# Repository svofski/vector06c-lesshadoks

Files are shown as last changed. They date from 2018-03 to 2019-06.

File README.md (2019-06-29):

ЛЕШАДОК ПОМПЕ
=============

ЛЕШАДОК ПОМПЕ (Les shadoks pompaient) is an expansion board for Вектор-06ц home computer from USSR era.

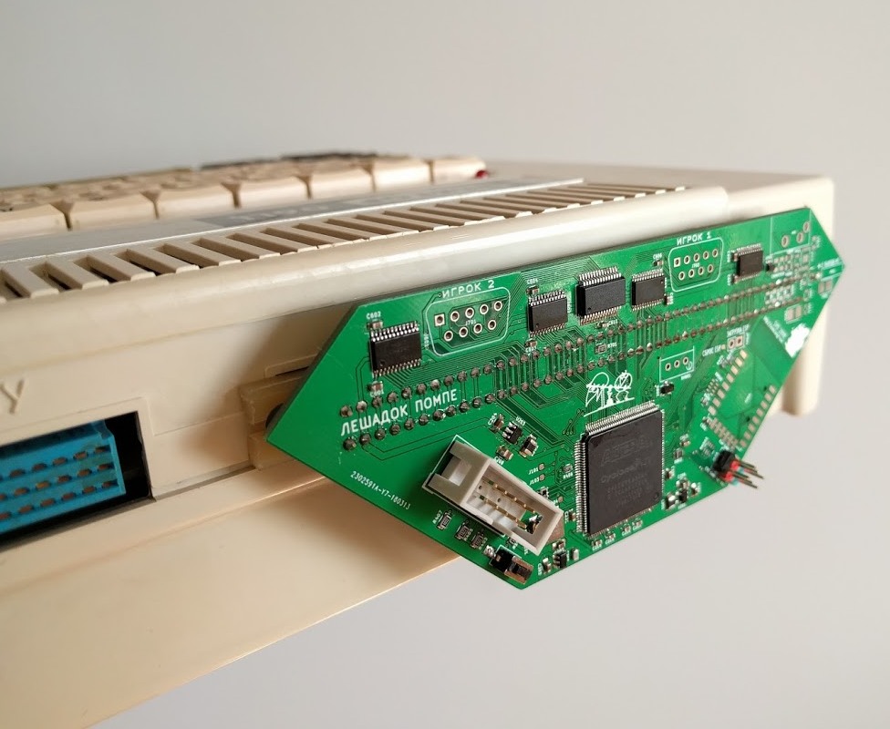
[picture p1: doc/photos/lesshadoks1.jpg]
ЛЕШАДОК ПОМПЕ


Features (real and planned):
  - [x] RAM disk expansion in SDRAM
  - [x] AY and other sound device emulation
  - [x] Joystick ports
  - [x] floppy disk emulator
  - [x] floppy images on SD card
  - [ ] floppy images downloaded from the internets
  - [x] ESP12F working as FPGA configurator
  - [x] ESP12F as user interface for SD card image selection
  - [ ] ESP12F for uploading floppy disk images to SDRAM
  - [ ] VI53 sound passthrough
  
Key hardware features:
  * Main chip: EP4CE6 Intel Cyclone IV device
  * 8MB SDRAM (working at 96MHz)
  * ESP12F module
  * Audio output with amplifier
  * Analog input for internal audio mixing (using LVDS sigma-delta ADC)

Board schematic
---------------
[Schematic](/kicad/shadok-cheap/shadok.pdf) (pdf)

Build instructions
------------------
This project consists of many parts and putting it together is not a simple task.
Here I wrote down some instructions primarily for myself to be able to remember
what to do. Good luck!

### PART 1 Building Cosmogol999 (esp8266 firmware)

1. Get the sources
```
git clone --recurse-submodules https://github.com/svofski/vector06c-lesshadoks
```

2. Prepare esp-open-sdk
Follow instructions at https://github.com/pfalcon/esp-open-sdk.
Mind the requirements, then get the SDK and build:
```
git clone --recursive --depth=1 https://github.com/pfalcon/esp-open-sdk.git
cd esp-open-sdk
make STANDALONE=y
```

After the toolchain is ready, do as it says:
```
export PATH=$HOME/esp-open-sdk/xtensa-lx106-elf/bin:$PATH
```
Also export SDK_BASE:
```
export SDK_BASE=$HOME/esp-open-sdk/ESP8266_NONOS_SDK-2.1.0-18-g61248df
```

3. Actually build

```
cd $HOME/vector06c-lesshadoks/esp8266/cosmogol999
make 
``` 

The firmware will be found in 
```
    rboot/firmware/rboot.bin
    firmware/shadki.bin
    blank_config.bin
```

6. Flash
```
make flash
```
This probably will do something destructive to your esp12f.

### PART 2 Building floppy emulator firmware

This one should be easy.
```
cd $HOME/vector06c-lesshadoks/6502
make
```

### PART 3 Building the FPGA programming files

1. Get and install Quartus Lite that supports Cyclone IV E (e.g. 17.1)

2. For the time being there is no makefile, so just open the project 
quartus/pompaient.qpf and press Ctrl-L.

### PART 4 Put it all together

???

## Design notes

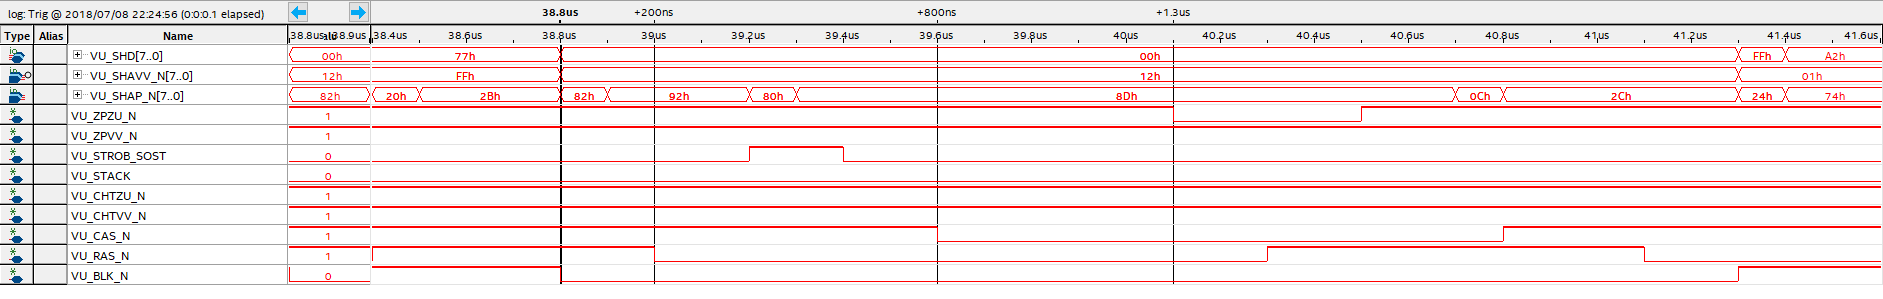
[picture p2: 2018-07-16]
doc/buscaptures/kvaz-write-to-1234-as-ram.png

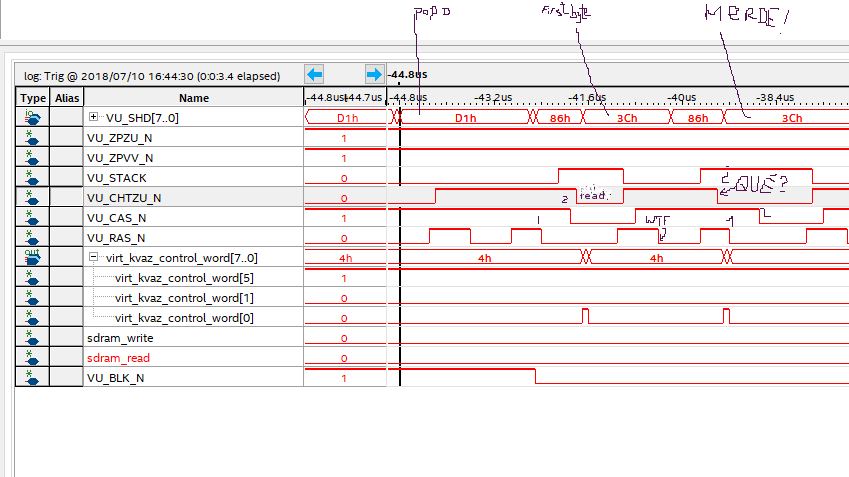
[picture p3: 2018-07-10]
doc/buscaptures/pop-merde.png

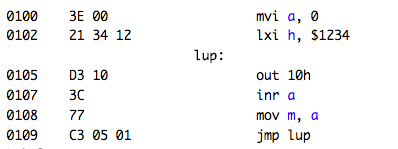
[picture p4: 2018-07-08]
doc/buscaptures/count-and-sta-code.png

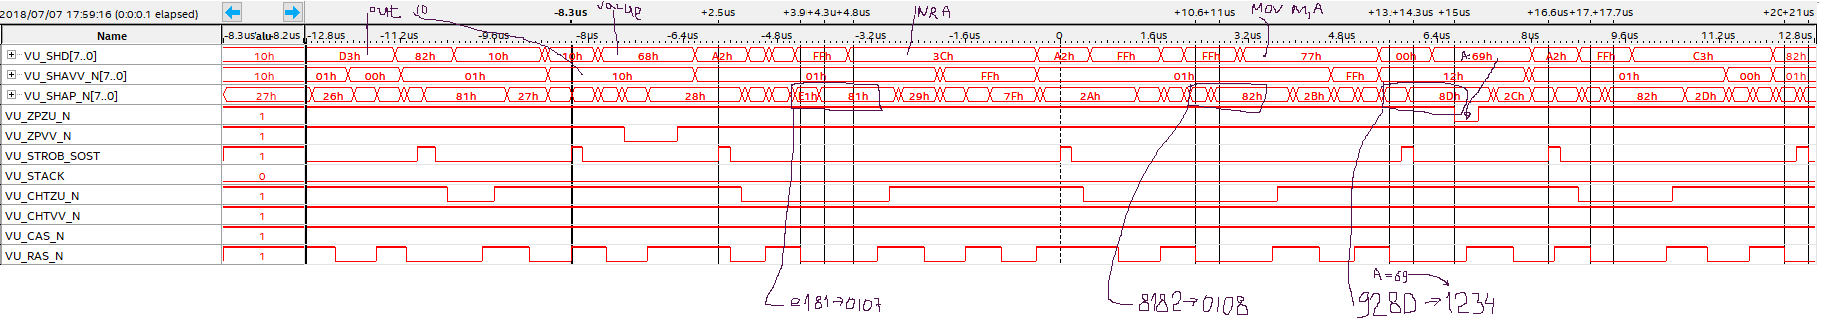
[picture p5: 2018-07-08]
doc/buscaptures/count-and-sta.png

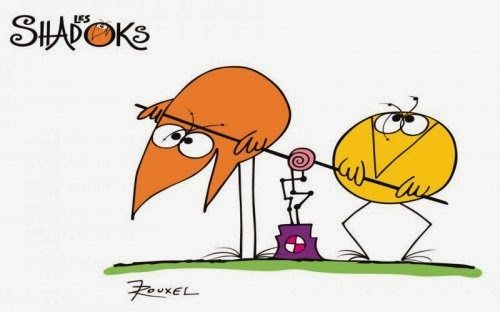
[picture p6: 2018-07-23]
esp8266/cosmogol999/html/shadoks/pompaient.jpg

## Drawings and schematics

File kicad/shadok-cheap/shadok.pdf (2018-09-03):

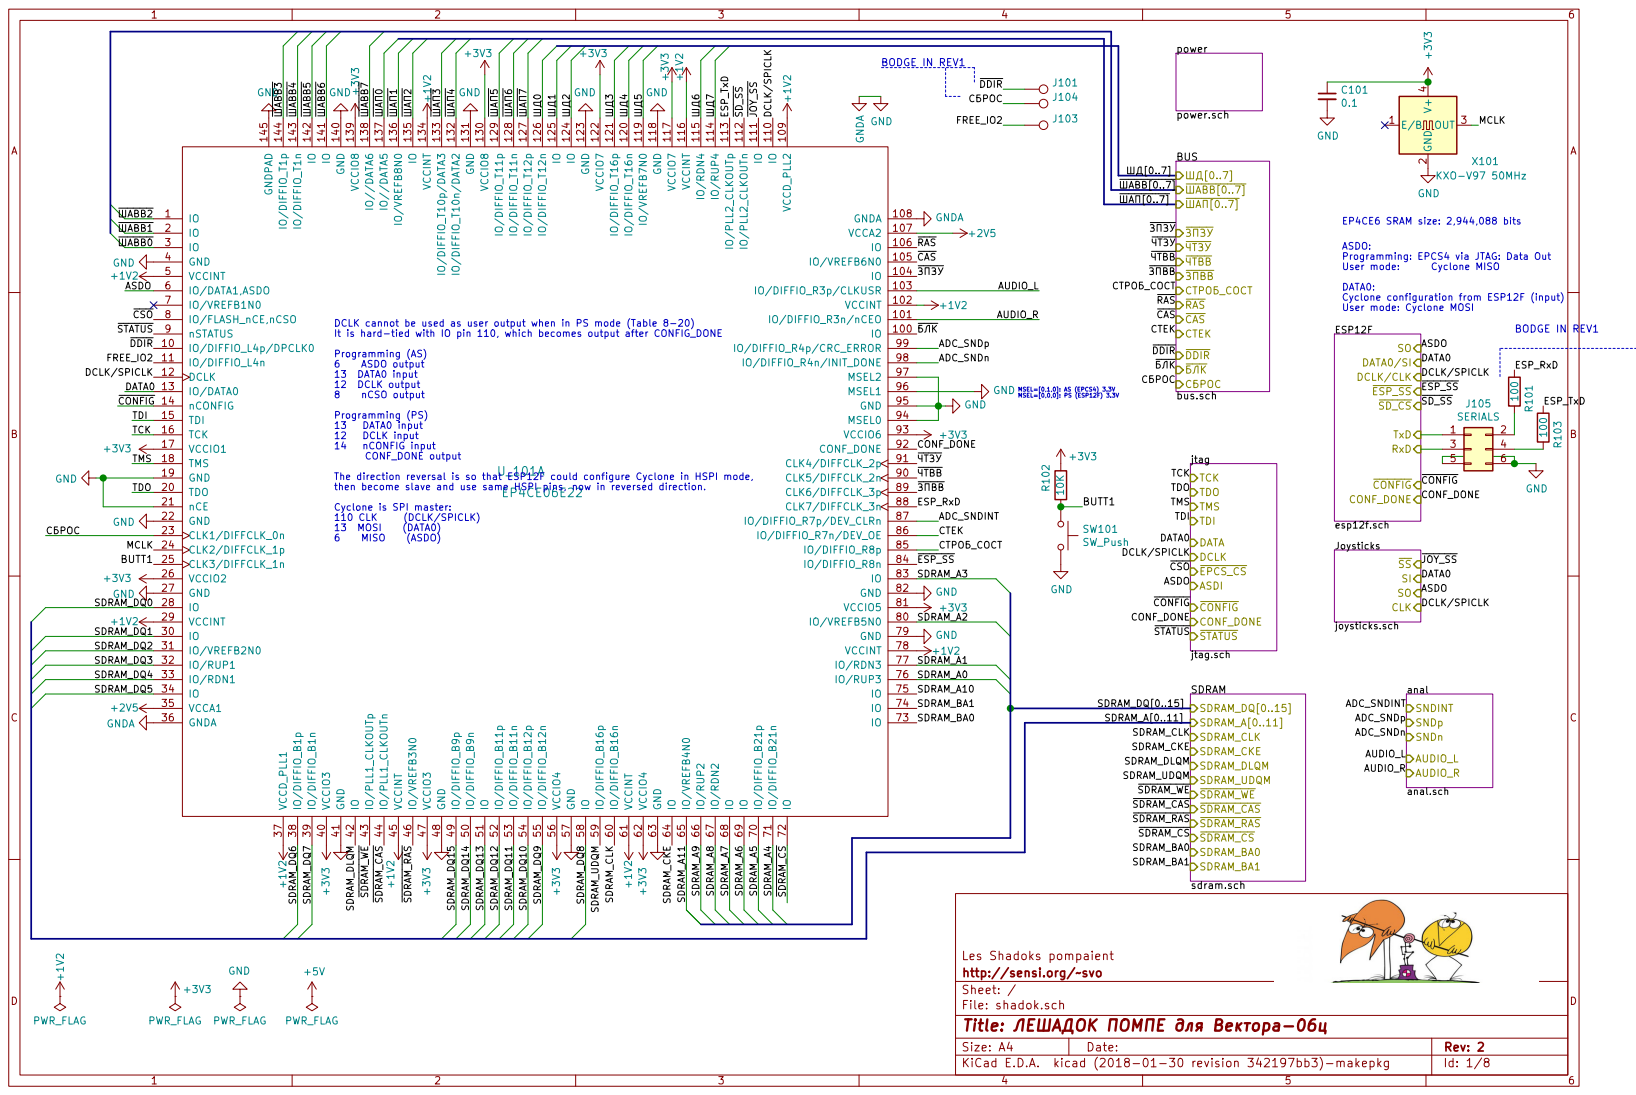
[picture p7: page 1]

BODGE IN REV1

EP4CE6 SRAM size: 2,944,088 bits DCLK cannot be used as user output when in PS mode (Table 8-20)

esp12f.sch DCLK/CLK DATA0/SI CONFIG

DATA0: Cyclone configuration from ESP12F (input) User mode: Cyclone MOSI DCLK/SPICLK DATA0 CONFIG

It is hard-tied with IO pin 110, which becomes output after CONFIG_DONE
Programming (AS) 6 ASDO output 13 DATA0 input 12 DCLK output 8 nCSO output Programming (PS) 13 DATA0 input 12 DCLK input 14 nCONFIG input

CONF_DONE output The direction reversal is so that ESP12F could configure Cyclone in HSPI mode,

joysticks.sch CLK
anal anal.sch SNDINT SNDp SNDn AUDIO_L AUDIO_R

Les Shadoks pompaient
File: shadok.sch Sheet: / http://sensi.org/svo

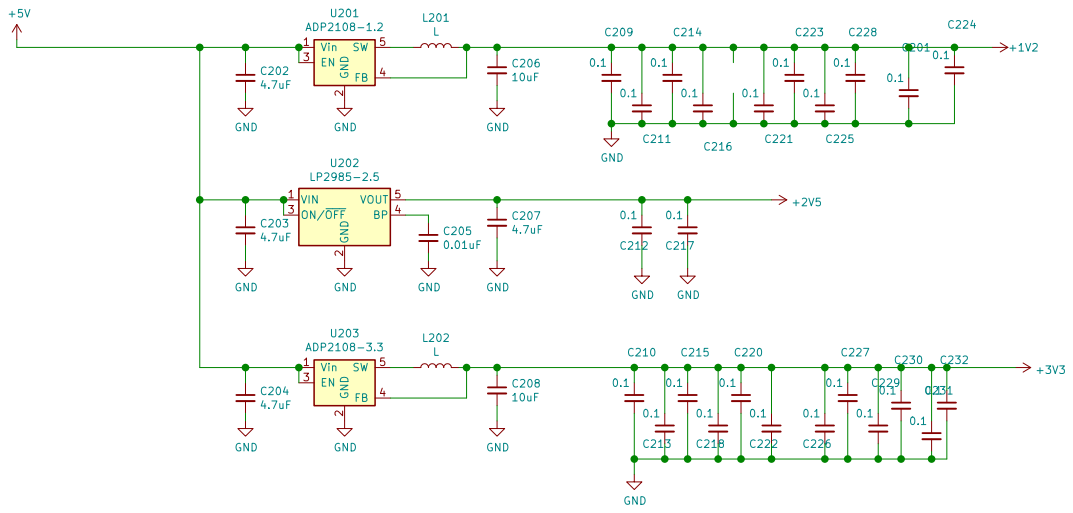
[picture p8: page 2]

2 EN 3 FB 4 SW 5 U201 ADP2108-1.2 Vin 1 GND
L GND GND GND

2 ON/OFF 3 BP 4 VOUT 5 U202

2 EN 3 FB 4 SW 5 U203 ADP2108-3.3 VIN 1 GND

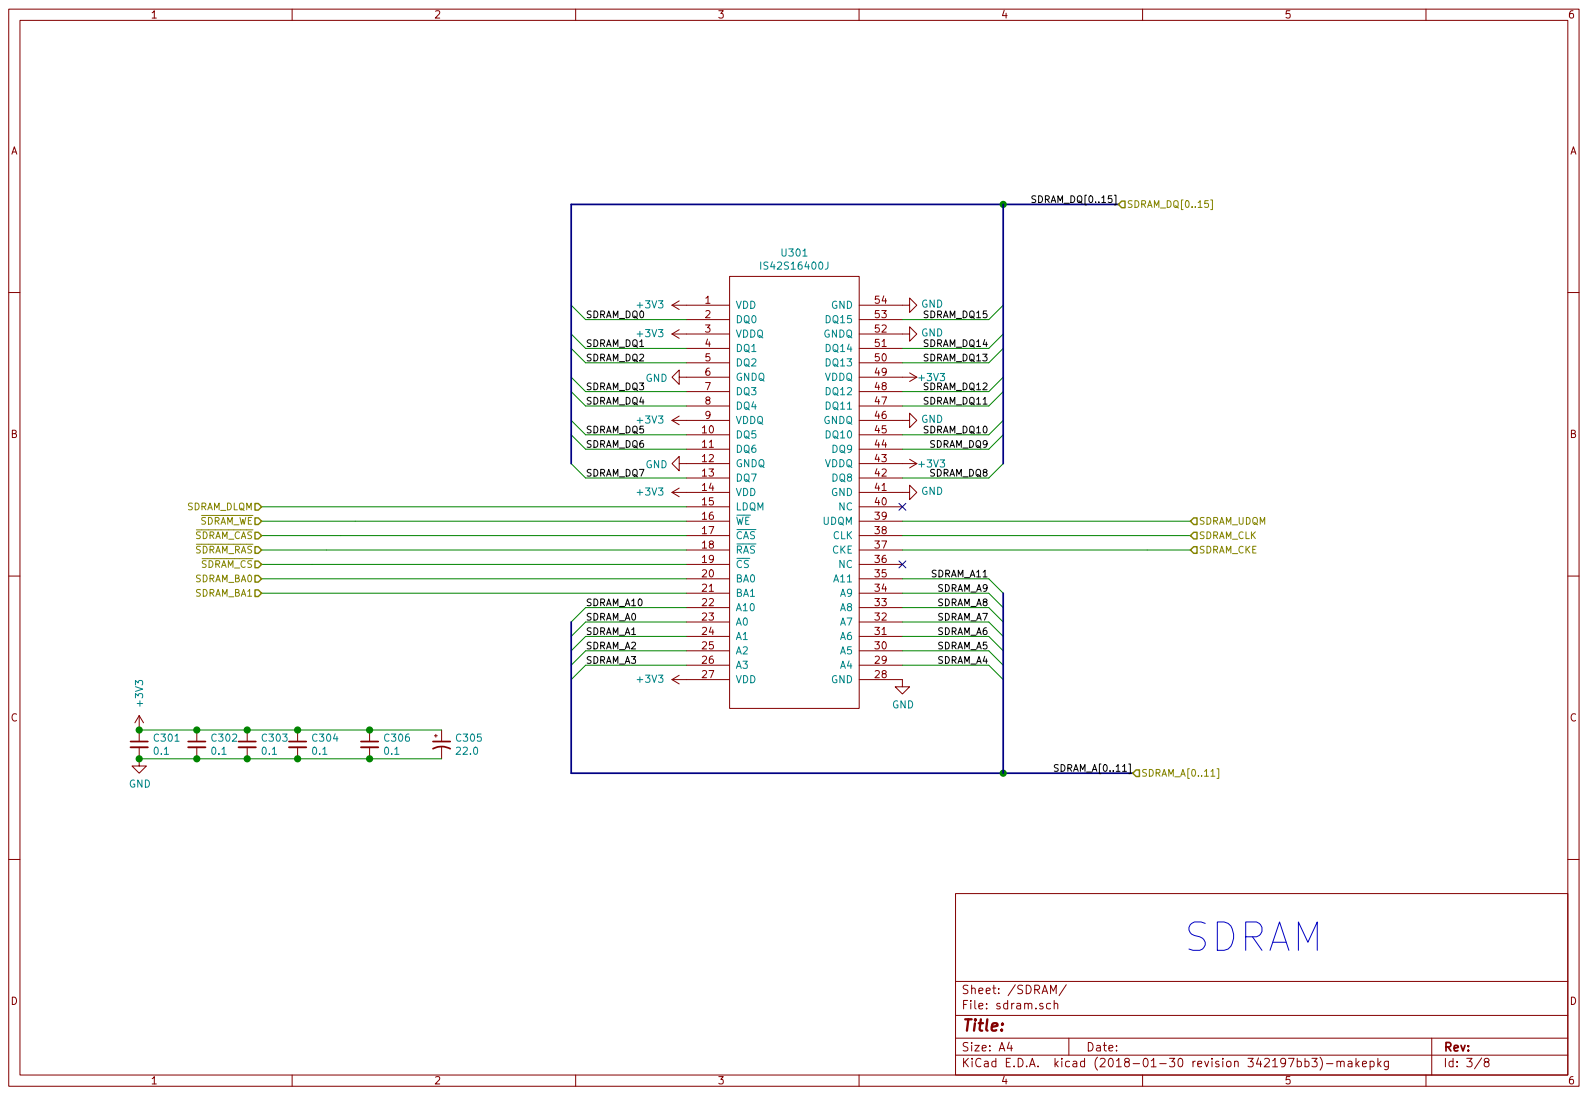
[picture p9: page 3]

Id: 3/8 Title: File: sdram.sch Sheet: /SDRAM/

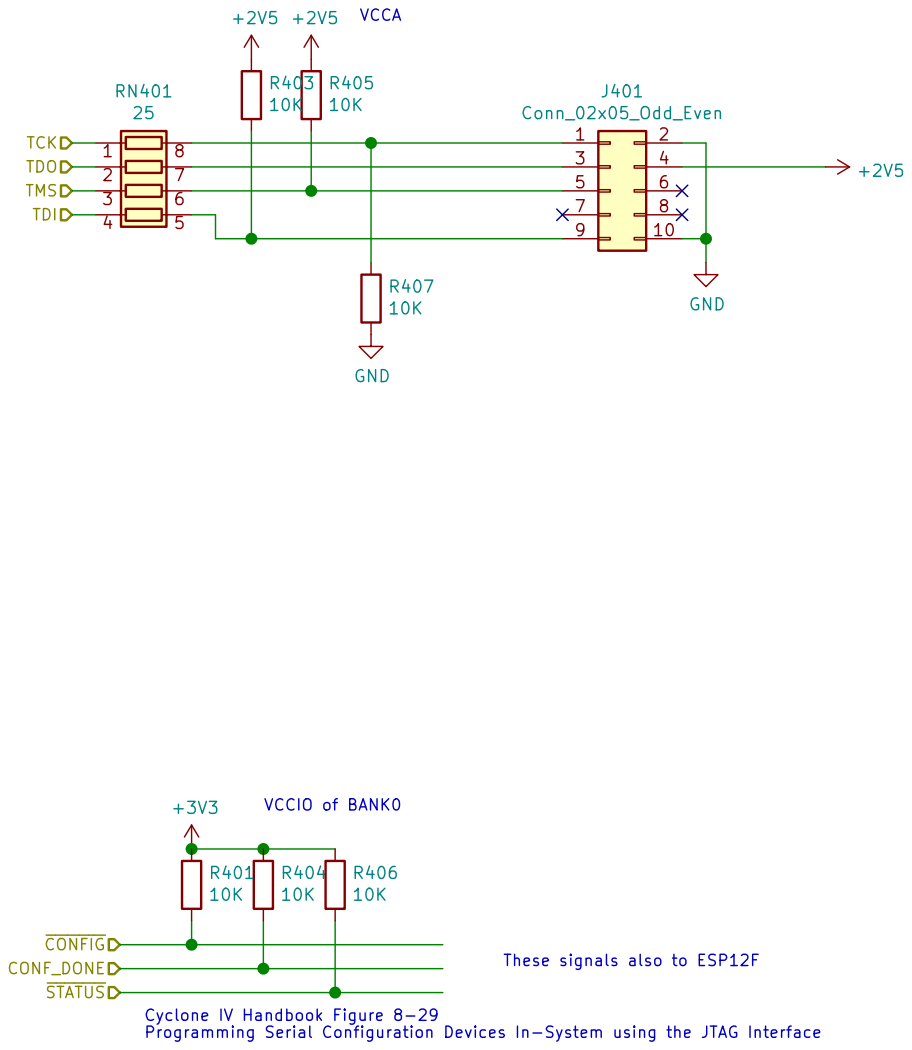
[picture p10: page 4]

7 | | 5 | 6 8 10
6 | | 7 9

These signals also to ESP12F R404

Programming Serial Configuration Devices In-System using the JTAG Interface

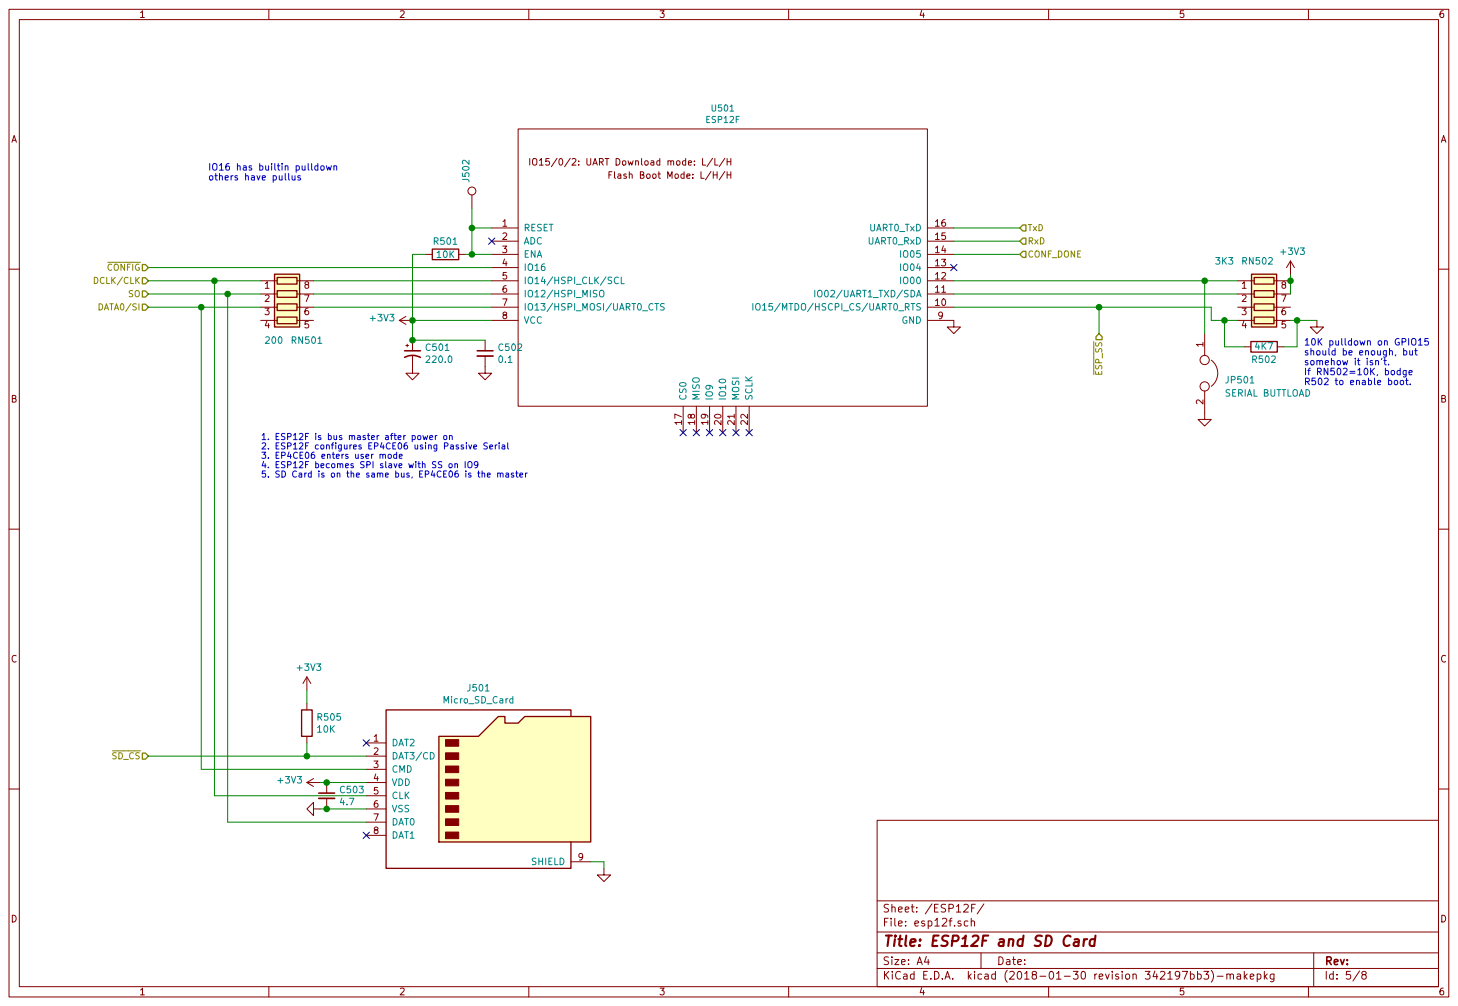
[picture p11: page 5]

should be enough, but somehow it isn't.
If RN502=10K, bodge R502 to enable boot.

1. ESP12F is bus master after power on
2. ESP12F configures EP4CE06 using Passive Serial 3. EP4CE06 enters user mode
4. ESP12F becomes SPI slave with SS on IO9

File: esp12f.sch Sheet: /ESP12F/
Id: 5/8 Title: ESP12F and SD Card

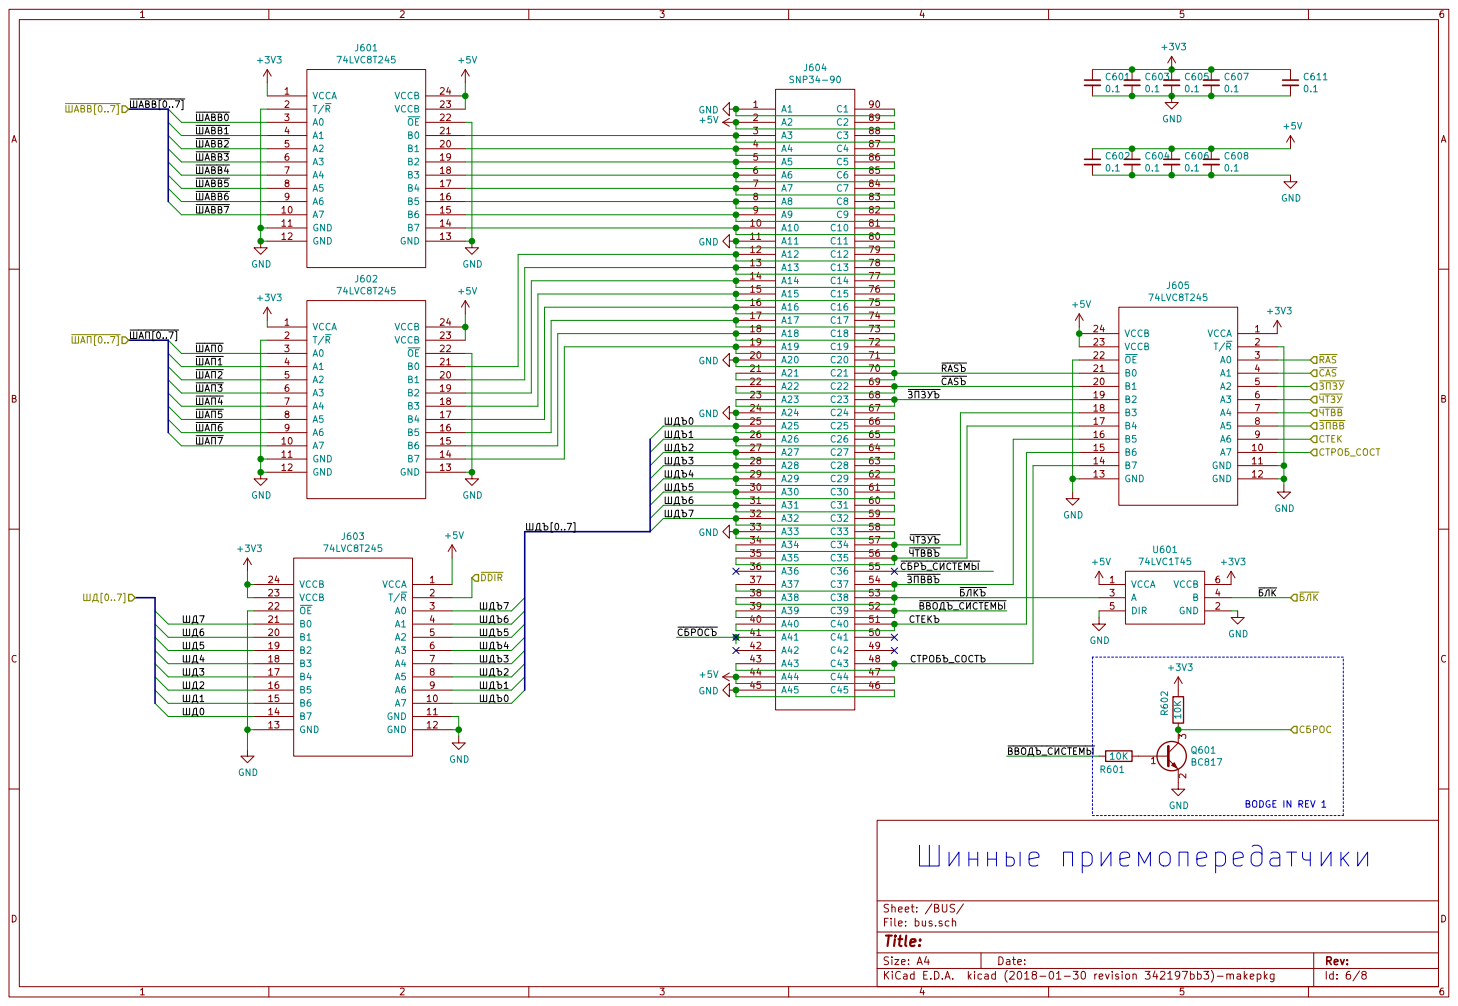
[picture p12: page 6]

J604 SNP34-90 GND GND GND GND GND GND

Id: 6/8 Title: File: bus.sch Sheet: /BUS/

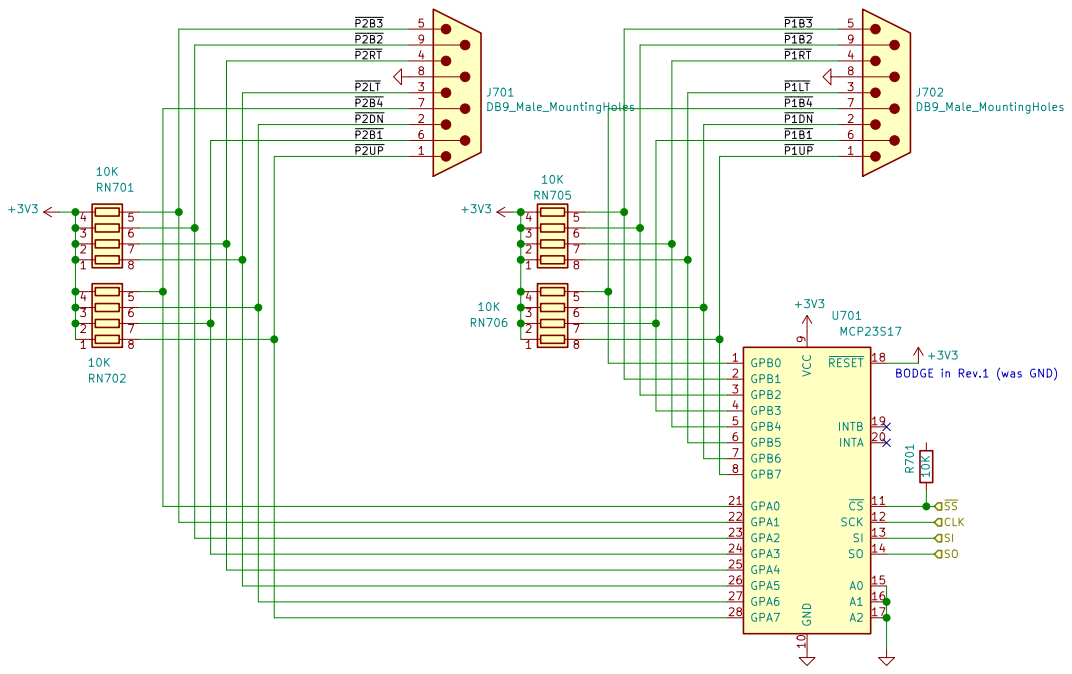
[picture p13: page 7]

File: joysticks.sch
Id: 7/8 Title: Joystick ports

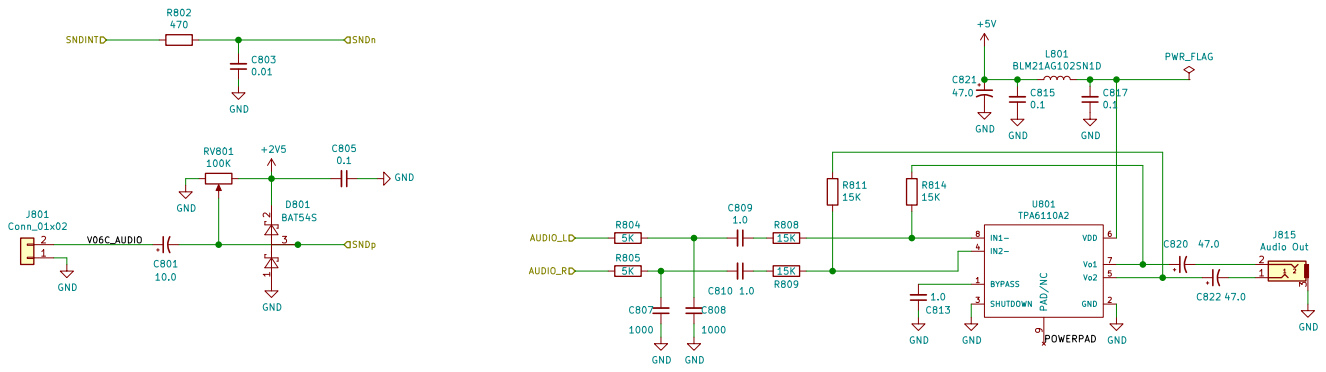
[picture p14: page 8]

File: anal.sch Sheet: /anal/
Id: 8/8 Title: Analog I/O

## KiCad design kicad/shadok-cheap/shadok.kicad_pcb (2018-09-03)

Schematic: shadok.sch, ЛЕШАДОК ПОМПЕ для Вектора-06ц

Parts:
C101: 0.1; C_0603
J101, J103, J104: TEST_1P; WIREPAD_SMD_TINY
J105: SERIALS; Pin_Header_Straight_2x03
R101, R103: 100; R_0805
R102: 10K; R_0805
SW101: SW_Push; SW_SPST_FSMSM
U_101: EP4CE06E22; Altera_EQFP-144_20x20mm_Pitch0.5mm
X101: KXO-V97 50MHz; KXO-V97

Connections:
+1V2: U_101.5, U_101.29, U_101.37, U_101.45, U_101.61, U_101.78, U_101.102, U_101.109, U_101.116, U_101.134; also elsewhere on the board
+2V5: U_101.35, U_101.107; also elsewhere on the board
+3V3: C101.1, R102.2, U_101.17, U_101.26, U_101.40, U_101.47, U_101.56, U_101.62, U_101.81, U_101.93, U_101.117, U_101.122, U_101.130, U_101.139, X101.4; also elsewhere on the board
/ADC_SNDINT: U_101.87; also elsewhere on the board
/ADC_SNDn: U_101.98; also elsewhere on the board
/ADC_SNDp: U_101.99; also elsewhere on the board
/ASDO: U_101.6; also elsewhere on the board
/AUDIO_L: U_101.103; also elsewhere on the board
/AUDIO_R: U_101.101; also elsewhere on the board
/BUTT1: R102.1, SW101.1, U_101.25
/CONF_DONE: U_101.92; also elsewhere on the board
/DATA0: U_101.13; also elsewhere on the board
/DCLK/SPICLK: U_101.12, U_101.110; also elsewhere on the board
/ESP12F/RxD: J105.3; also elsewhere on the board
/ESP12F/TxD: J105.1; also elsewhere on the board
/ESP_RxD: R101.1, U_101.88
/ESP_TxD: R103.1, U_101.113
/FREE_IO2: J103.1, U_101.11
/MCLK: U_101.24, X101.3
/SDRAM_A0: U_101.76; also elsewhere on the board
/SDRAM_A1: U_101.77; also elsewhere on the board
/SDRAM_A2: U_101.80; also elsewhere on the board
/SDRAM_A3: U_101.83; also elsewhere on the board
/SDRAM_A4: U_101.71; also elsewhere on the board
/SDRAM_A5: U_101.70; also elsewhere on the board
/SDRAM_A6: U_101.69; also elsewhere on the board
/SDRAM_A7: U_101.68; also elsewhere on the board
/SDRAM_A8: U_101.67; also elsewhere on the board
/SDRAM_A9: U_101.66; also elsewhere on the board
/SDRAM_A10: U_101.75; also elsewhere on the board
/SDRAM_A11: U_101.65; also elsewhere on the board
/SDRAM_BA0: U_101.73; also elsewhere on the board
/SDRAM_BA1: U_101.74; also elsewhere on the board
/SDRAM_CKE: U_101.64; also elsewhere on the board
/SDRAM_CLK: U_101.60; also elsewhere on the board
/SDRAM_DLQM: U_101.42; also elsewhere on the board
/SDRAM_DQ0: U_101.28; also elsewhere on the board
/SDRAM_DQ1: U_101.30; also elsewhere on the board
/SDRAM_DQ2: U_101.31; also elsewhere on the board
/SDRAM_DQ3: U_101.32; also elsewhere on the board
/SDRAM_DQ4: U_101.33; also elsewhere on the board
/SDRAM_DQ5: U_101.34; also elsewhere on the board
/SDRAM_DQ6: U_101.38; also elsewhere on the board
/SDRAM_DQ7: U_101.39; also elsewhere on the board
/SDRAM_DQ8: U_101.58; also elsewhere on the board
/SDRAM_DQ9: U_101.55; also elsewhere on the board
/SDRAM_DQ10: U_101.54; also elsewhere on the board
/SDRAM_DQ11: U_101.53; also elsewhere on the board
/SDRAM_DQ12: U_101.52; also elsewhere on the board
/SDRAM_DQ13: U_101.51; also elsewhere on the board
/SDRAM_DQ14: U_101.50; also elsewhere on the board
/SDRAM_DQ15: U_101.49; also elsewhere on the board
/SDRAM_UDQM: U_101.59; also elsewhere on the board
/TCK: U_101.16; also elsewhere on the board
/TDI: U_101.15; also elsewhere on the board
/TDO: U_101.20; also elsewhere on the board
/TMS: U_101.18; also elsewhere on the board
/~CAS: U_101.105; also elsewhere on the board
/~CONFIG: U_101.14; also elsewhere on the board
/~CSO: U_101.8
/~DDIR: J101.1, U_101.10; also elsewhere on the board
/~ESP_SS: U_101.84; also elsewhere on the board
/~JOY_SS: U_101.111; also elsewhere on the board
/~RAS: U_101.106; also elsewhere on the board
/~SDRAM_CAS: U_101.44; also elsewhere on the board
/~SDRAM_CS: U_101.72; also elsewhere on the board
/~SDRAM_RAS: U_101.46; also elsewhere on the board
/~SDRAM_WE: U_101.43; also elsewhere on the board
/~SD_SS: U_101.112; also elsewhere on the board
/~STATUS: U_101.9; also elsewhere on the board
/~БЛК: U_101.100; also elsewhere on the board
/~ЗПВВ: U_101.89; also elsewhere on the board
/~ЗПЗУ: U_101.104; also elsewhere on the board
/~ЧТВВ: U_101.90; also elsewhere on the board
/~ЧТЗУ: U_101.91; also elsewhere on the board
/~ШАВВ0: U_101.3; also elsewhere on the board
/~ШАВВ1: U_101.2; also elsewhere on the board
/~ШАВВ2: U_101.1; also elsewhere on the board
/~ШАВВ3: U_101.144; also elsewhere on the board
/~ШАВВ4: U_101.143; also elsewhere on the board
/~ШАВВ5: U_101.142; also elsewhere on the board
/~ШАВВ6: U_101.141; also elsewhere on the board
/~ШАВВ7: U_101.138; also elsewhere on the board
/~ШАП0: U_101.137; also elsewhere on the board
/~ШАП1: U_101.136; also elsewhere on the board
/~ШАП2: U_101.135; also elsewhere on the board
/~ШАП3: U_101.133; also elsewhere on the board
/~ШАП4: U_101.132; also elsewhere on the board
/~ШАП5: U_101.129; also elsewhere on the board
/~ШАП6: U_101.128; also elsewhere on the board
/~ШАП7: U_101.127; also elsewhere on the board
/СБРОС: J104.1, U_101.23; also elsewhere on the board
/СТЕК: U_101.86; also elsewhere on the board
/СТРОБ_СОСТ: U_101.85; also elsewhere on the board
/ШД0: U_101.126; also elsewhere on the board
/ШД1: U_101.125; also elsewhere on the board
/ШД2: U_101.124; also elsewhere on the board
/ШД3: U_101.121; also elsewhere on the board
/ШД4: U_101.120; also elsewhere on the board
/ШД5: U_101.119; also elsewhere on the board
/ШД6: U_101.115; also elsewhere on the board
/ШД7: U_101.114; also elsewhere on the board
GND: C101.2, J105.5, J105.6, SW101.2, U_101.4, U_101.19, U_101.21, U_101.22, U_101.27, U_101.36, U_101.41, U_101.48, U_101.57, U_101.63, U_101.79, U_101.82, U_101.94, U_101.95, U_101.96, U_101.97, U_101.108, U_101.118, U_101.123, U_101.131, U_101.140, U_101.145, X101.2; also elsewhere on the board
unnamed: J105.2, R101.2
unnamed: J105.4, R103.2

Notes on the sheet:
MSEL=[0,1,0]: AS (EPCS4) 3.3V MSEL=[0,0,0]: PS (ESP12F) 3.3V
ASDO: Programming: EPCS4 via JTAG: Data Out User mode: Cyclone MISO DATA0: Cyclone configuration from ESP12F (input) User mode: Cyclone MOSI
EP4CE6 SRAM size: 2,944,088 bits
DCLK cannot be used as user output when in PS mode (Table 8-20) It is hard-tied with IO pin 110, which becomes output after CONFIG_DONE Programming (AS) 6 ASDO output 13 DATA0 input 12 DCLK output 8 nCSO output Programming (PS) 13 DATA0 input 12 DCLK input 14 nCONFIG input CONF_DONE output The dire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
BODGE IN REV1

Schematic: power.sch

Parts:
C201, C209, C210, C211, C212, C213, C214, C215, C216, C217, C218, C220, C221, C222, C223, C224, C225, C226, C227, C228, C229, C230, C231, C232: 0.1; C_0603
C202, C203, C204, C207: 4.7uF; C_0805
C205: 0.01uF; C_0603
C206, C208: 10uF; C_0805
L201, L202: L; R_1206
U201: ADP2108-1.2; TSOT-23-5
U202: LP2985-2.5; SOT-23-5
U203: ADP2108-3.3; TSOT-23-5

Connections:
+1V2: C201.1, C206.1, C209.1, C211.1, C214.1, C216.1, C221.1, C223.1, C224.1, C225.1, C228.1, L201.2, U201.4; also elsewhere on the board
+2V5: C207.1, C212.1, C217.1, U202.5 (VOUT); also elsewhere on the board
+3V3: C208.1, C210.1, C213.1, C215.1, C218.1, C220.1, C222.1, C226.1, C227.1, C229.1, C230.1, C231.1, C232.1, L202.2, U203.4; also elsewhere on the board
+5V: C202.1, C203.1, C204.1, U201.1, U201.3, U202.1 (VIN), U202.3 (ON/~OFF~), U203.1, U203.3; also elsewhere on the board
GND: C201.2, C202.2, C203.2, C204.2, C205.2, C206.2, C207.2, C208.2, C209.2, C210.2, C211.2, C212.2, C213.2, C214.2, C215.2, C216.2, C217.2, C218.2, C220.2, C221.2, C222.2, C223.2, C224.2, C225.2, C226.2, C227.2, C228.2, C229.2, C230.2, C231.2, C232.2, U201.2, U202.2 (GND), U203.2; also elsewhere on the board
unnamed: C205.1, U202.4 (BP)
unnamed: L201.1, U201.5
unnamed: L202.1, U203.5

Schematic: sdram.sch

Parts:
C301, C302, C303, C304, C306: 0.1; C_0603
C305: 22.0; CP_Tantalum_Case-B_EIA-3528-21_Reflow
U301: IS42S16400J; TSOP-2-54-0.8

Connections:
+3V3: C301.1, C302.1, C303.1, C304.1, C305.1, C306.1, U301.1, U301.3, U301.9, U301.14, U301.27, U301.43, U301.49; also elsewhere on the board
/SDRAM_A0: U301.23; also elsewhere on the board
/SDRAM_A1: U301.24; also elsewhere on the board
/SDRAM_A2: U301.25; also elsewhere on the board
/SDRAM_A3: U301.26; also elsewhere on the board
/SDRAM_A4: U301.29; also elsewhere on the board
/SDRAM_A5: U301.30; also elsewhere on the board
/SDRAM_A6: U301.31; also elsewhere on the board
/SDRAM_A7: U301.32; also elsewhere on the board
/SDRAM_A8: U301.33; also elsewhere on the board
/SDRAM_A9: U301.34; also elsewhere on the board
/SDRAM_A10: U301.22; also elsewhere on the board
/SDRAM_A11: U301.35; also elsewhere on the board
/SDRAM_BA0: U301.20; also elsewhere on the board
/SDRAM_BA1: U301.21; also elsewhere on the board
/SDRAM_CKE: U301.37; also elsewhere on the board
/SDRAM_CLK: U301.38; also elsewhere on the board
/SDRAM_DLQM: U301.15; also elsewhere on the board
/SDRAM_DQ0: U301.2; also elsewhere on the board
/SDRAM_DQ1: U301.4; also elsewhere on the board
/SDRAM_DQ2: U301.5; also elsewhere on the board
/SDRAM_DQ3: U301.7; also elsewhere on the board
/SDRAM_DQ4: U301.8; also elsewhere on the board
/SDRAM_DQ5: U301.10; also elsewhere on the board
/SDRAM_DQ6: U301.11; also elsewhere on the board
/SDRAM_DQ7: U301.13; also elsewhere on the board
/SDRAM_DQ8: U301.42; also elsewhere on the board
/SDRAM_DQ9: U301.44; also elsewhere on the board
/SDRAM_DQ10: U301.45; also elsewhere on the board
/SDRAM_DQ11: U301.47; also elsewhere on the board
/SDRAM_DQ12: U301.48; also elsewhere on the board
/SDRAM_DQ13: U301.50; also elsewhere on the board
/SDRAM_DQ14: U301.51; also elsewhere on the board
/SDRAM_DQ15: U301.53; also elsewhere on the board
/SDRAM_UDQM: U301.39; also elsewhere on the board
/~SDRAM_CAS: U301.17; also elsewhere on the board
/~SDRAM_CS: U301.19; also elsewhere on the board
/~SDRAM_RAS: U301.18; also elsewhere on the board
/~SDRAM_WE: U301.16; also elsewhere on the board
GND: C301.2, C302.2, C303.2, C304.2, C305.2, C306.2, U301.6, U301.12, U301.28, U301.41, U301.46, U301.52, U301.54; also elsewhere on the board

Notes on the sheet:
SDRAM

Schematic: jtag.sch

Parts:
J401: Conn_02x05_Odd_Even; IDC-Header_2x05_Pitch2.54mm_Straight
R401, R404, R406: 10K; R_0603
R403, R405, R407: 10K; R_0805
RN401: 25; R_Array_Concave_4x0603

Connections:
+2V5: J401.4, R403.2, R405.2; also elsewhere on the board
+3V3: R401.2, R404.2, R406.2; also elsewhere on the board
/CONF_DONE: R404.1; also elsewhere on the board
/TCK: RN401.1; also elsewhere on the board
/TDI: RN401.4; also elsewhere on the board
/TDO: RN401.2; also elsewhere on the board
/TMS: RN401.3; also elsewhere on the board
/~CONFIG: R401.1; also elsewhere on the board
/~STATUS: R406.1; also elsewhere on the board
GND: J401.2, J401.10, R407.1; also elsewhere on the board
unnamed: J401.1, R407.2, RN401.8
unnamed: J401.3, RN401.7
unnamed: J401.5, R405.1, RN401.6
unnamed: J401.9, R403.1, RN401.5

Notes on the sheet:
VCCIO of BANK0
Cyclone IV Handbook Figure 8-29 Programming Serial Configuration Devices In-System using the JTAG Interface
VCCA
These signals also to ESP12F

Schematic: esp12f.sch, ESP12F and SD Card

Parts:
C501: 220.0; CP_Tantalum_Case-D_EIA-7343-31_Reflow
C502: 0.1; C_0603
C503: 4.7; C_0805
J501: Micro_SD_Card; Conn_uSDcard
J502: TEST_1P; WIREPAD_SMD_TINY
JP501: SERIAL BUTTLOAD; Pin_Header_Straight_1x02
R501: 10K; R_0603
R502: 4K7; R_0603
R505: 10K; R_0805
RN501: 200; R_Array_Concave_4x0603
RN502: 3K3; R_Array_Concave_4x0603
U501: ESP12F; ESP-12E_SMD

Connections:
+3V3: C501.1, C502.1, C503.1, J501.4, R501.2, R505.1, RN502.7, RN502.8, U501.8; also elsewhere on the board
/ASDO: J501.7, RN501.2; also elsewhere on the board
/CONF_DONE: U501.14; also elsewhere on the board
/DATA0: J501.3, RN501.3; also elsewhere on the board
/DCLK/SPICLK: J501.5, RN501.1; also elsewhere on the board
/ESP12F/RxD: U501.15; also elsewhere on the board
/ESP12F/TxD: U501.16; also elsewhere on the board
/~CONFIG: U501.4; also elsewhere on the board
/~ESP_SS: R502.1, RN502.4, U501.10; also elsewhere on the board
/~SD_SS: J501.2, R505.2; also elsewhere on the board
GND: C501.2, C502.2, C503.2, J501.6, J501.9, JP501.2, R502.2, RN502.5, U501.9; also elsewhere on the board
unnamed: J502.1, R501.1, U501.1, U501.3
unnamed: JP501.1, RN502.1, U501.12
unnamed: RN501.6, U501.7
unnamed: RN501.7, U501.6
unnamed: RN501.8, U501.5
unnamed: RN502.2, U501.11

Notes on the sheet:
1. ESP12F is bus master after power on 2. ESP12F configures EP4CE06 using Passive Serial 3. EP4CE06 enters user mode 4. ESP12F becomes SPI slave with SS on IO9 5. SD Card is on the same bus, EP4CE06 is the master
IO16 has builtin pulldown others have pullus
10K pulldown on GPIO15 should be enough, but somehow it isn't. If RN502=10K, bodge R502 to enable boot.

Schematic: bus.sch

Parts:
C601, C602, C603, C604, C605, C606, C607, C608, C611: 0.1; C_0603
J601, J602, J603, J605: 74LVC8T245; TSSOP-24_4.4x7.8mm_Pitch0.65mm
J604: SNP34-90; СНП34С-90В-В(SNP34S)
Q601: BC817; SOT-23
R601, R602: 10K; R_0805
U601: 74LVC1T45; SOT-363_SC-70-6

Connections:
+3V3: C601.1, C603.1, C605.1, C607.1, C611.1, J601.1, J602.1, J603.23, J603.24, J605.1, R602.2, U601.6; also elsewhere on the board
+5V: C602.1, C604.1, C606.1, C608.1, J601.23, J601.24, J602.23, J602.24, J603.1, J604.2, J604.44, J604.47, J604.89, J605.23, J605.24, U601.1; also elsewhere on the board
/BUS/~CASЪ: J604.22, J604.69, J605.20
/BUS/~RASЪ: J604.21, J604.70, J605.21
/BUS/~БЛКЪ: J604.38, J604.53, U601.3
/BUS/~ВВОДЪ_СИСТЕМЫ: J604.39, J604.52, R601.2
/BUS/~ЗПВВЪ: J604.37, J604.54, J605.16
/BUS/~ЗПЗУЪ: J604.23, J604.68, J605.19
/BUS/~СБРОСЪ: J604.41
/BUS/~СБРЪ_СИСТЕМЫ: J604.55
/BUS/~ЧТВВЪ: J604.35, J604.56, J605.17
/BUS/~ЧТЗУЪ: J604.34, J604.57, J605.18
/BUS/СТЕКЪ: J604.40, J604.51, J605.15
/BUS/СТРОБЪ_СОСТЪ: J604.43, J604.48, J605.14
/BUS/ШДЪ0: J603.10, J604.25, J604.66
/BUS/ШДЪ1: J603.9, J604.26, J604.65
/BUS/ШДЪ2: J603.8, J604.27, J604.64
/BUS/ШДЪ3: J603.7, J604.28, J604.63
/BUS/ШДЪ4: J603.6, J604.29, J604.62
/BUS/ШДЪ5: J603.5, J604.30, J604.61
/BUS/ШДЪ6: J603.4, J604.31, J604.60
/BUS/ШДЪ7: J603.3, J604.32, J604.59
/~CAS: J605.4; also elsewhere on the board
/~DDIR: J603.2; also elsewhere on the board
/~RAS: J605.3; also elsewhere on the board
/~БЛК: U601.4; also elsewhere on the board
/~ЗПВВ: J605.8; also elsewhere on the board
/~ЗПЗУ: J605.5; also elsewhere on the board
/~ЧТВВ: J605.7; also elsewhere on the board
/~ЧТЗУ: J605.6; also elsewhere on the board
/~ШАВВ0: J601.3; also elsewhere on the board
/~ШАВВ1: J601.4; also elsewhere on the board
/~ШАВВ2: J601.5; also elsewhere on the board
/~ШАВВ3: J601.6; also elsewhere on the board
/~ШАВВ4: J601.7; also elsewhere on the board
/~ШАВВ5: J601.8; also elsewhere on the board
/~ШАВВ6: J601.9; also elsewhere on the board
/~ШАВВ7: J601.10; also elsewhere on the board
/~ШАП0: J602.3; also elsewhere on the board
/~ШАП1: J602.4; also elsewhere on the board
/~ШАП2: J602.5; also elsewhere on the board
/~ШАП3: J602.6; also elsewhere on the board
/~ШАП4: J602.7; also elsewhere on the board
/~ШАП5: J602.8; also elsewhere on the board
/~ШАП6: J602.9; also elsewhere on the board
/~ШАП7: J602.10; also elsewhere on the board
/СБРОС: Q601.3, R602.1; also elsewhere on the board
/СТЕК: J605.9; also elsewhere on the board
/СТРОБ_СОСТ: J605.10; also elsewhere on the board
/ШД0: J603.14; also elsewhere on the board
/ШД1: J603.15; also elsewhere on the board
/ШД2: J603.16; also elsewhere on the board
/ШД3: J603.17; also elsewhere on the board
/ШД4: J603.18; also elsewhere on the board
/ШД5: J603.19; also elsewhere on the board
/ШД6: J603.20; also elsewhere on the board
/ШД7: J603.21; also elsewhere on the board
GND: C601.2, C602.2, C603.2, C604.2, C605.2, C606.2, C607.2, C608.2, C611.2, J601.2, J601.11, J601.12, J601.13, J601.22, J602.2, J602.11, J602.12, J602.13, J602.22, J603.11, J603.12, J603.13, J603.22, J604.1, J604.11, J604.20, J604.24, J604.33, J604.45, J604.46, J604.58, J604.67, J604.71, J604.80, J604.90, J605.2, J605.11, J605.12, J605.13, J605.22, Q601.2, U601.2, U601.5; also elsewhere on the board
unnamed: J601.14, J604.10, J604.81
unnamed: J601.15, J604.9, J604.82
unnamed: J601.16, J604.8, J604.83
unnamed: J601.17, J604.7, J604.84
unnamed: J601.18, J604.6, J604.85
unnamed: J601.19, J604.5, J604.86
unnamed: J601.20, J604.4, J604.87
unnamed: J601.21, J604.3, J604.88
unnamed: J602.14, J604.19, J604.72
unnamed: J602.15, J604.18, J604.73
unnamed: J602.16, J604.17, J604.74
unnamed: J602.17, J604.16, J604.75
unnamed: J602.18, J604.15, J604.76
unnamed: J602.19, J604.14, J604.77
unnamed: J602.20, J604.13, J604.78
unnamed: J602.21, J604.12, J604.79
unnamed: Q601.1, R601.1

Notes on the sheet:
Шинные приемопередатчики
BODGE IN REV 1

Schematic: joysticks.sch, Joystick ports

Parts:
J701, J702: DB9_Male_MountingHoles; DSUB-9_Male_Vertical_Pitch2.77x2.84mm
R701: 10K; R_0805
RN701, RN702, RN705, RN706: 10K; R_Array_Concave_4x0603
U701: MCP23S17; SSOP-28_5.3x10.2mm_Pitch0.65mm

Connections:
+3V3: RN701.1, RN701.2, RN701.3, RN701.4, RN702.1, RN702.2, RN702.3, RN702.4, RN705.1, RN705.2, RN705.3, RN705.4, RN706.1, RN706.2, RN706.3, RN706.4, U701.9, U701.18; also elsewhere on the board
/ASDO: U701.14; also elsewhere on the board
/DATA0: U701.13; also elsewhere on the board
/DCLK/SPICLK: U701.12; also elsewhere on the board
/Joysticks/~P1B1: J702.6, RN706.7, U701.4
/Joysticks/~P1B2: J702.9, RN705.6, U701.3
/Joysticks/~P1B3: J702.5, RN705.5, U701.2
/Joysticks/~P1B4: J702.7, RN706.5, U701.1
/Joysticks/~P1DN: J702.2, RN706.6, U701.7
/Joysticks/~P1LT: J702.3, RN705.8, U701.6
/Joysticks/~P1RT: J702.4, RN705.7, U701.5
/Joysticks/~P1UP: J702.1, RN706.8, U701.8
/Joysticks/~P2B1: J701.6, RN702.7, U701.24
/Joysticks/~P2B2: J701.9, RN701.6, U701.23
/Joysticks/~P2B3: J701.5, RN701.5, U701.22
/Joysticks/~P2B4: J701.7, RN702.5, U701.21
/Joysticks/~P2DN: J701.2, RN702.6, U701.27
/Joysticks/~P2LT: J701.3, RN701.8, U701.26
/Joysticks/~P2RT: J701.4, RN701.7, U701.25
/Joysticks/~P2UP: J701.1, RN702.8, U701.28
/~JOY_SS: R701.1, U701.11; also elsewhere on the board
GND: J701.8, J702.8, U701.10, U701.15, U701.16, U701.17; also elsewhere on the board

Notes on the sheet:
BODGE in Rev.1 (was GND)

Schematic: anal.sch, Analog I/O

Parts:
C801: 10.0; CP_Tantalum_Case-B_EIA-3528-21_Reflow
C803: 0.01; C_0603
C805, C815, C817: 0.1; C_0603
C807, C808: 1000; C_0805
C809, C810, C813: 1.0; C_0805
C820, C822: 47.0; CP_Tantalum_Case-B_EIA-3528-21_Reflow
C821: 47.0; CP_Tantalum_Case-D_EIA-7343-31_Reflow
D801: BAT54S; SOT-23
J801: Conn_01x02; Socket_Strip_Angled_2x01
J815: Audio Out; ST-215N-04
L801: BLM21AG102SN1D; R_0805
R802: 470; R_0805
R804, R805: 5K; R_0805
R808, R809, R811, R814: 15K; R_0805
RV801: 100K; Potentiometer_Bourns_3296W_3-8Zoll_Inline_ScrewUp
U801: TPA6110A2; MSOP-8-1EP_3x3mm_Pitch0.65mm

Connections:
+2V5: C805.2, D801.2, RV801.1; also elsewhere on the board
+5V: C815.2, C821.1, L801.1; also elsewhere on the board
/ADC_SNDINT: R802.2; also elsewhere on the board
/ADC_SNDn: C803.2, R802.1; also elsewhere on the board
/ADC_SNDp: C801.2, D801.3, RV801.2; also elsewhere on the board
/AUDIO_L: R804.2; also elsewhere on the board
/AUDIO_R: R805.2; also elsewhere on the board
/anal/POWERPAD: U801.9
/anal/V06C_AUDIO: C801.1, J801.2
GND: C803.1, C805.1, C807.1, C808.1, C813.1, C815.1, C817.1, C821.2, D801.1, J801.1, J815.3, RV801.3, U801.2, U801.3; also elsewhere on the board
unnamed: C807.2, C810.2, R805.1
unnamed: C808.2, C809.2, R804.1
unnamed: C809.1, R808.2
unnamed: C810.1, R809.2
unnamed: C813.2, U801.1
unnamed: C817.2, L801.2, U801.6
unnamed: C820.1, R814.2, U801.7
unnamed: C820.2, J815.2
unnamed: C822.1, R811.2, U801.5
unnamed: C822.2, J815.1
unnamed: R808.1, R814.1, U801.8
unnamed: R809.1, R811.1, U801.4

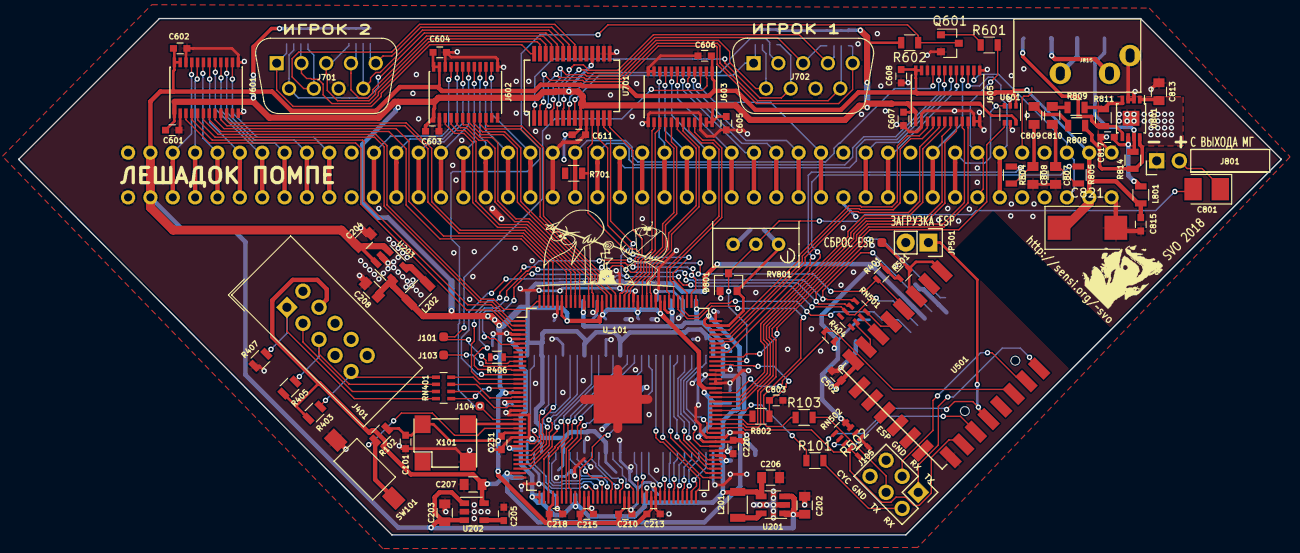
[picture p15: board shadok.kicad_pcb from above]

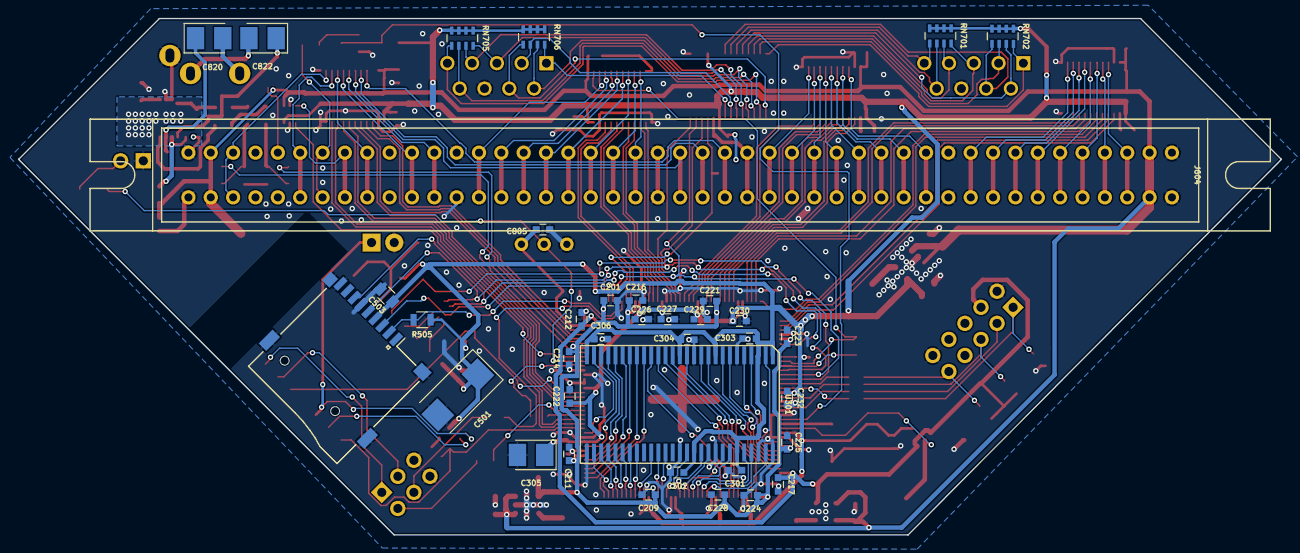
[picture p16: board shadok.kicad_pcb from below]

Board: 2 copper layers, 141.2 x 57.8 mm, 126 parts (37 on the bottom side), 182 nets.

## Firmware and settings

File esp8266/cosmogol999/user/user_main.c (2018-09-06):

#include <string.h>
#include <stdio.h>

#include <esp8266.h>
#include <httpd.h>
#include <httpdespfs.h>
#include <cgiwifi.h>
#include <auth.h>
#include <espfs.h>
#include <captdns.h>
#include <webpages-espfs.h>
#include <cgiwebsocket.h>

#include "rboot-api.h"
#include "stdout.h"
#include "io.h"
#include "cgi.h"
#include "cgispiffs.h"
#include "cgirboot.h"
#include "cgifloppy.h"
#include "inifile.h"

#include "uart.h"
#include "slave.h"

#define AP_SSID "ЛЕШАДОК ПОМПЕ"
#define AP_PSK "pompaient"

HttpdBuiltInUrl builtInUrls[]={
	{"*", cgiRedirectApClientToHostname, "esp8266.nonet"},
	{"/", cgiRedirect, "/index.tpl"},
        {"/fpga/", cgiRedirect, "/fpga/index.tpl"},
        {"/fpga/index.tpl", cgiEspFsTemplate, tplFPGA},
        {"/fpga/upload", cgiUploadFile, NULL},
        {"/fpga/dir", cgiDirectory, NULL},
        {"/fpga/delete", cgiDelete, NULL},
        {"/fpga/bootname", cgiSelectBoot, NULL},

	{"/led.tpl", cgiEspFsTemplate, tplLed},
	{"/index.tpl", cgiEspFsTemplate, tplCounter},
	{"/led.cgi", cgiLed, NULL},

	{"/flash/", cgiRedirect, "/flash/index.html"},
	{"/flash/upload", cgiUploadFirmware2, NULL},
	{"/flash/reboot", cgiRebootFirmware2, NULL},

	{"/wifi", cgiRedirect, "/wifi/wifi.tpl"},
	{"/wifi/", cgiRedirect, "/wifi/wifi.tpl"},
	{"/wifi/wifiscan.cgi", cgiWiFiScan, NULL},
	{"/wifi/wifi.tpl", cgiEspFsTemplate, tplWlan},
	{"/wifi/connect.cgi", cgiWiFiConnect, NULL},
	{"/wifi/connstatus.cgi", cgiWiFiConnStatus, NULL},
	{"/wifi/setmode.cgi", cgiWiFiSetMode, NULL},

        {"/floppy", cgiRedirect, "/floppy/index.html"},
        {"/floppy/", cgiRedirect, "/floppy/index.html"},
        {"/floppy/catalog", cgiFloppyCatalog, NULL},
        {"/floppy/select", cgiFloppySelect, NULL},

	{"*", cgiEspFsHook, NULL}, //Catch-all cgi function for the filesystem
	{NULL, NULL, NULL}
};

#if 0
void ICACHE_FLASH_ATTR wifiInit() {
    struct ip_info ap_ip;
    switch(wifi_get_opmode()) {
        case STATIONAP_MODE:
        case SOFTAP_MODE:
            IP4_ADDR(&ap_ip.ip, 172, 16, 0, 1);
            IP4_ADDR(&ap_ip.gw, 0, 0, 0, 0);
            IP4_ADDR(&ap_ip.netmask, 255, 255, 0, 0);
            wifi_set_ip_info(1, &ap_ip);

            struct softap_config ap_config = {
                .ssid = AP_SSID,
                .ssid_hidden = 0,
                .channel = 3,
                .ssid_len = strlen(AP_SSID),
                .authmode = AUTH_WPA_WPA2_PSK,
                .password = AP_PSK,
                .max_connection = 3,
                .beacon_interval = 250,
            };
            wifi_softap_set_config(&ap_config);

            //ip_addr_t first_client_ip;
            //IP4_ADDR(&first_client_ip, 172, 16, 0, 2);
            //dhcpserver_start(&first_client_ip, 4);
            //dhcpserver_set_dns(&ap_ip.ip);
            //dhcpserver_set_router(&ap_ip.ip);
            break;
        case STATION_MODE:
            break;
        default:
            break;
    }
}
#else
void ICACHE_FLASH_ATTR wifiInit() 
{
    wifi_set_opmode_current(STATION_MODE);
    struct station_config sc;
    strcpy((char *)sc.ssid, "shadki-ap");
    strcpy((char *)sc.password, "jepompedoncjesuis");
    wifi_station_set_config(&sc); 
}
#endif

ICACHE_FLASH_ATTR void setup_rboot()
{
    printf("rboot_get_current_rom: %d\n", rboot_get_current_rom());
    rboot_config rconfig = rboot_get_config();
    printf("rboot magic=%x version=%d mode=%d current_rom=%d gpio_rom=%d "
            "count=%d\n", rconfig.magic, rconfig.version, rconfig.mode, 
            rconfig.current_rom, rconfig.gpio_rom, rconfig.count);
    for (int i = 0; i < MAX_ROMS; ++i) {
        printf("%c @%08x\n", (i==rconfig.current_rom)?'*':' ', rconfig.roms[i]);
    }

    if (rconfig.roms[1] != 0x102000) {
        printf("rboot config is probably correct for someone else. Fixing it.\n");
        rconfig.roms[1] = 0x102000;
        rboot_set_config(&rconfig);
    }
}

LOCAL os_timer_t spislave_timer;
LOCAL void ICACHE_FLASH_ATTR spislave_init(void *arg)
{
    os_timer_disarm(&spislave_timer);
    slave_init();
}

ICACHE_FLASH_ATTR
void test_inifile_printall()
{
    const char * s = inifile_get_boot();
    printf("inifile_get_boot(): [%s]\n", s ? s : "(null)");
    s = inifile_get_mode();
    printf("inifile_get_mode(): [%s]\n", s ? s : "(null)");
    s = inifile_get_fdd();
    printf("inifile_get_fdd(): [%s]\n", s ? s : "(null)");
    s = inifile_get_rom();
    printf("inifile_get_rom(): [%s]\n", s ? s : "(null)");
}

ICACHE_FLASH_ATTR
void test_inifile()
{
    test_inifile_printall();

    printf("set mode=rom\n");
    inifile_set_mode("rom");
    test_inifile_printall();

    printf("set fdd=cockblock.fdd\n");
    inifile_set_fdd("cockblock.fdd");
    test_inifile_printall();

    printf("set rom=fucksock.rom\n");
    inifile_set_rom("fucksock.rom");
    test_inifile_printall();

    printf("set mode=fdd\n");
    inifile_set_mode("fdd");
    test_inifile_printall();
}

//Main routine. Initialize stdout, the I/O, filesystem and the webserver and we're done.
ICACHE_FLASH_ATTR void user_init(void) {
    stdoutInit();
    printf("\nbloody hell\n");
    wifiInit();

    ioInit();
    spiffs_init();

    //test_inifile();

    spiffs_configure_fpga();
    io_shutdown_spi();

    setup_rboot();
    captdnsInit();
    espFsInit((void*)(webpages_espfs_start));
    httpdInit(builtInUrls, 80);

    //wifi_set_sleep_type(MODEM_SLEEP_T);
    //wifi_set_sleep_type(LIGHT_SLEEP_T);
    // no sleep == no interference when waking up
    wifi_set_sleep_type(NONE_SLEEP_T);
    system_phy_set_max_tpw(1);

    os_timer_disarm(&spislave_timer); 
    os_timer_setfn(&spislave_timer, (os_timer_func_t *) spislave_init, NULL);
    os_timer_arm(&spislave_timer, 2500, 0);

    printf("\nuser_init() done\n");
}

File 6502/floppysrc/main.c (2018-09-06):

// ====================================================================
//                         VECTOR-06C FPGA REPLICA
//
//              Copyright (C) 2007-2014, Viacheslav Slavinsky
//
// This code is distributed under modified BSD license. 
// For complete licensing information see LICENSE.TXT.
// -------------------------------------------------------------------- 
//
// An open implementation of Vector-06C home computer
//
// Author: Viacheslav Slavinsky, http://sensi.org/~svo
// 
// Source file: main.c
//
// FDC workhorse main module.
//
// --------------------------------------------------------------------

#include <string.h>

#include "serial.h"
#include "specialio.h"
#include "integer.h"

#include "diskio.h"
#include "tff.h"

#include "timer.h"
#include "config.h"
#include "slave.h"
#include "osd.h"
#include "philes.h"
#include "bootes.h"
#include "menu.h"

char* cnotice1 = "LES SHADOKS POMPAIENT FOR VECTOR-06C";
char* cnotice2 = "(C)2008-2018  VIACHESLAV SLAVINSKY";

/*---------------------------------------------------------*/
/* User Provided Timer Function for FatFs module           */
/*---------------------------------------------------------*/
/* This is a real time clock service to be called from     */
/* FatFs module. Any valid time must be returned even if   */
/* the system does not support a real time clock.          */
DWORD get_fattime (void)
{
    return 0;
}


BYTE* Buffer = (BYTE *)0x0200;

void print_result(DRESULT result) {
    switch (result) {
        case 0:
            break;
        default:
            ser_puts(" :( ");
            print_hex((BYTE)result);
            ser_nl();
            break;
    }
}

void fill_filename(char *buf, char *fname) {
    memset(buf, 0, 12);
    strncpy(buf, fname, 12);
}

#define CHECKRESULT {/*if (result) break;*/}

extern char* ptrfile;

unsigned char * sdram_byte = (unsigned char *)(0x5000);

void sdram_probe()
{
    int i;
    for (i = 0; i < 16; ++i) {
        sdram_byte[i] = i;
    }
    for (i = 0; i < 16; ++i) {
        print_hex(sdram_byte[i]);
        ser_puts(" ");
    }
    ser_nl();
}

void main(void) {
    BYTE res;

    DRESULT result;
    FRESULT fresult;
    int i;
   
    SLAVE_STATUS = 0;
    GREEN_LEDS = 0xC3;

    ser_puts("@");
#if !SIMULATION
    delay2(10);
#endif
    ser_nl(); ser_puts(cnotice1); 
    ser_nl(); ser_puts(cnotice2);
    ser_nl(); 

    sdram_probe();

    // delay so that the original boot has time to cough up, 
    // it gets messy otherwise (make it civil and coroutine-ish later)
    delay2(50);
    load_boot();

    thrall(Buffer);
    print_result(result);
    ser_puts("\r\nWTF?");
}

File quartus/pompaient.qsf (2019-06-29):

# -------------------------------------------------------------------------- #
#
# Copyright (C) 2017  Intel Corporation. All rights reserved.
# Your use of Intel Corporation's design tools, logic functions
# and other software and tools, and its AMPP partner logic
# functions, and any output files from any of the foregoing
# (including device programming or simulation files), and any
# associated documentation or information are expressly subject
# to the terms and conditions of the Intel Program License
# Subscription Agreement, the Intel Quartus Prime License Agreement,
# the Intel FPGA IP License Agreement, or other applicable license
# agreement, including, without limitation, that your use is for
# the sole purpose of programming logic devices manufactured by
# Intel and sold by Intel or its authorized distributors.  Please
# refer to the applicable agreement for further details.
#
# -------------------------------------------------------------------------- #
#
# Quartus Prime
# Version 17.1.0 Build 590 10/25/2017 SJ Lite Edition
# Date created = 00:32:32  February 01, 2018
#
# -------------------------------------------------------------------------- #
#
# Notes:
#
# 1) The default values for assignments are stored in the file:
#		pompaient_assignment_defaults.qdf
#    If this file doesn't exist, see file:
#		assignment_defaults.qdf
#
# 2) Altera recommends that you do not modify this file. This
#    file is updated automatically by the Quartus Prime software
#    and any changes you make may be lost or overwritten.
#
# -------------------------------------------------------------------------- #


set_global_assignment -name FAMILY "Cyclone IV E"
set_global_assignment -name DEVICE EP4CE6E22C8
set_global_assignment -name TOP_LEVEL_ENTITY lesshadoks_top
set_global_assignment -name ORIGINAL_QUARTUS_VERSION 17.1.0
set_global_assignment -name PROJECT_CREATION_TIME_DATE "00:52:52  JUNE 28, 2018"
set_global_assignment -name LAST_QUARTUS_VERSION "18.1.0 Lite Edition"
set_global_assignment -name PROJECT_OUTPUT_DIRECTORY output_files
set_global_assignment -name MIN_CORE_JUNCTION_TEMP 0
set_global_assignment -name MAX_CORE_JUNCTION_TEMP 85
set_global_assignment -name DEVICE_FILTER_PACKAGE TQFP
set_global_assignment -name ERROR_CHECK_FREQUENCY_DIVISOR 1
set_global_assignment -name EDA_SIMULATION_TOOL "ModelSim-Altera (Verilog)"
set_global_assignment -name EDA_TIME_SCALE "1 ps" -section_id eda_simulation
set_global_assignment -name EDA_OUTPUT_DATA_FORMAT "VERILOG HDL" -section_id eda_simulation
set_global_assignment -name POWER_PRESET_COOLING_SOLUTION "23 MM HEAT SINK WITH 200 LFPM AIRFLOW"
set_global_assignment -name POWER_BOARD_THERMAL_MODEL "NONE (CONSERVATIVE)"

set_location_assignment PIN_28 -to DRAM_DQ[0]
set_location_assignment PIN_30 -to DRAM_DQ[1]
set_location_assignment PIN_31 -to DRAM_DQ[2]
set_location_assignment PIN_32 -to DRAM_DQ[3]
set_location_assignment PIN_33 -to DRAM_DQ[4]
set_location_assignment PIN_34 -to DRAM_DQ[5]
set_location_assignment PIN_38 -to DRAM_DQ[6]
set_location_assignment PIN_39 -to DRAM_DQ[7]
set_location_assignment PIN_58 -to DRAM_DQ[8]
set_location_assignment PIN_55 -to DRAM_DQ[9]
set_location_assignment PIN_54 -to DRAM_DQ[10]
set_location_assignment PIN_53 -to DRAM_DQ[11]
set_location_assignment PIN_52 -to DRAM_DQ[12]
set_location_assignment PIN_51 -to DRAM_DQ[13]
set_location_assignment PIN_50 -to DRAM_DQ[14]
set_location_assignment PIN_49 -to DRAM_DQ[15]
set_location_assignment PIN_76 -to DRAM_ADDR[0]
set_location_assignment PIN_77 -to DRAM_ADDR[1]
set_location_assignment PIN_80 -to DRAM_ADDR[2]
set_location_assignment PIN_83 -to DRAM_ADDR[3]
set_location_assignment PIN_71 -to DRAM_ADDR[4]
set_location_assignment PIN_70 -to DRAM_ADDR[5]
set_location_assignment PIN_69 -to DRAM_ADDR[6]
set_location_assignment PIN_68 -to DRAM_ADDR[7]
set_location_assignment PIN_67 -to DRAM_ADDR[8]
set_location_assignment PIN_66 -to DRAM_ADDR[9]
set_location_assignment PIN_75 -to DRAM_ADDR[10]
set_location_assignment PIN_65 -to DRAM_ADDR[11]
set_location_assignment PIN_43 -to DRAM_WE_N
set_location_assignment PIN_44 -to DRAM_CAS_N
set_location_assignment PIN_46 -to DRAM_RAS_N
set_location_assignment PIN_60 -to DRAM_CLK
set_location_assignment PIN_64 -to DRAM_CKE
set_location_assignment PIN_72 -to DRAM_CS_N
set_location_assignment PIN_73 -to DRAM_BA_0
set_location_assignment PIN_74 -to DRAM_BA_1
set_location_assignment PIN_42 -to DRAM_LDQM
set_location_assignment PIN_59 -to DRAM_UDQM

set_global_assignment -name ENABLE_OCT_DONE OFF
set_global_assignment -name ENABLE_CONFIGURATION_PINS OFF
set_global_assignment -name ENABLE_BOOT_SEL_PIN OFF
set_global_assignment -name STRATIXV_CONFIGURATION_SCHEME "PASSIVE SERIAL"
set_global_assignment -name USE_CONFIGURATION_DEVICE OFF
set_global_assignment -name CRC_ERROR_OPEN_DRAIN OFF
set_global_assignment -name STRATIX_DEVICE_IO_STANDARD "3.3-V LVTTL"
set_global_assignment -name OUTPUT_IO_TIMING_NEAR_END_VMEAS "HALF VCCIO" -rise
set_global_assignment -name OUTPUT_IO_TIMING_NEAR_END_VMEAS "HALF VCCIO" -fall
set_global_assignment -name OUTPUT_IO_TIMING_FAR_END_VMEAS "HALF SIGNAL SWING" -rise
set_global_assignment -name OUTPUT_IO_TIMING_FAR_END_VMEAS "HALF SIGNAL SWING" -fall
set_global_assignment -name CYCLONEII_RESERVE_NCEO_AFTER_CONFIGURATION "USE AS REGULAR IO"
set_global_assignment -name RESERVE_DATA0_AFTER_CONFIGURATION "USE AS REGULAR IO"
set_global_assignment -name RESERVE_DATA1_AFTER_CONFIGURATION "USE AS REGULAR IO"
set_global_assignment -name RESERVE_FLASH_NCE_AFTER_CONFIGURATION "USE AS REGULAR IO"
set_global_assignment -name RESERVE_DCLK_AFTER_CONFIGURATION "USE AS REGULAR IO"
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

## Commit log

2018-03-09 frist commut
    [anal.sch, bus.sch, esp12f.sch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]
2018-03-09 fixed the fuckups from the first version
    had to remove video module
    [anal.sch, bus.sch, esp12f.sch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]
2018-03-13 version 2 with all the required signals
    [anal.sch, bus.sch, esp12f.sch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]
2018-07-16 first working version
    kvaz in sdram
    AY emulation
    [anal.sch, bus.sch, shadok.kicad_pcb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]
2018-07-16 schematic sheet update + pdf
    [anal.sch, shadok.sch]
2018-07-17 fixed reset debounce
    it was held for too long, so first commands programming kvaz were likely to be
    ignored
    [pompaient.qsf]
2018-07-17 sdram arbitre for zpu or anything really WIP
    [bus.sch, shadok.kicad_pcb, shadok.sch]
2018-07-20 updated schematics
    reset bodge documented
2018-07-26 fine, but impossible to reduce tx power
    esp-open-rtos does not provide system_phy_set_max_tpw(), which makes it
    impossible to reduce output power and interference on v06c display
    [user_main.c]
2018-07-29 esp-open-sdk version
    * seems to build, work, ota-update, spiffs-file-upload just fine
    * exhibits strange forgetfulness of wifi settings after power down
    * was hard to build but has much less mysteries that the esp-open-rtos
    version
    * actual fpga configuration in the borat not yet tested
2018-07-29 noos sdk works
    no interference when sleep is disabled
    [cgispiffs.c, fpga.c, gpio16.c]
2018-07-31 switched cc65 to vector06cc branch
2018-08-01 documented bodge pulldown R502 across RN502
    [bus.sch, esp12f.sch, shadok.kicad_pcb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]
2018-08-03 +floppy +arbitre
    * kdtest still passes ok
    * floppy mounts sd card, but does not talk to the host
2018-08-04 reads data but problem with status or seek
    signaltap verified that the data are correct.
    seek parameters HST appear to mismatch though:
    track looks correct (beginning of directory)
    head seems ok (starting with 1)
    sector begins ok but then fails to advance.
    MDOS reports
    BDOS ERROR ON A: DISK ERROR
    O = 13 PC=7076H
    ST= 40 T= 8 S= 1... 13..
    IGNORE (Y/N) ?
    [pompaient.qsf, wd1793.v]
2018-08-11 spi slave wip
2018-08-18 move heatshrink to flash
2018-08-18 disk image selector works with a dummy arduino soc
2018-08-21 web interface for floppy selection works, kinda
    The only excuse for this shitty commit is to get a working demo for CC'2018.
    * a bit more robust state handling in the esp8266
    * timeouts on both sides, so that nothing lingers forever hopefully
    * delayed spi slave initialisation seems to help with reboots on bootup
    * floppy/spi.v works at 24MHz for sd card, at 12MHz for ESP12F
    Checking this in because there's no time to make it better. In the
    future, the protocol between SoC and ESP should be changed. Both SoC and
    ESP8266 sides are insanely sloppy. This is only for the demo.
    Why the fuck ESP keeps resetting is beyond my understanding. It's just
    shit. It helps to initialise spi slave a b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
    [slave.c, spi_slave.c, user_main.c]
2018-08-21 verilog parts supplementing the last commit
    [bus.sch, esp12f.sch]
2018-09-03 joystick "C" on ports 2e/2f works well
    [bus.sch, joysticks.sch, shadok.kicad_pcb]
2018-09-06 wip: rom selector, fdd A/B... NOT WORKING YET
    * inifile in ESP12F for persisting selections, modes, etc
    * SoC requests initial images, modes from ESP12F at boot
    * new SD-card directory structure:
    /V06C/FDD
    /V06C/EDD
    /V06C/ROM
    /V06C/BOOT
    [cgispiffs.c, fpga.c, inifile.c]
2019-06-29 build instructions and some makefile fixes
    [pompaient.qsf]
